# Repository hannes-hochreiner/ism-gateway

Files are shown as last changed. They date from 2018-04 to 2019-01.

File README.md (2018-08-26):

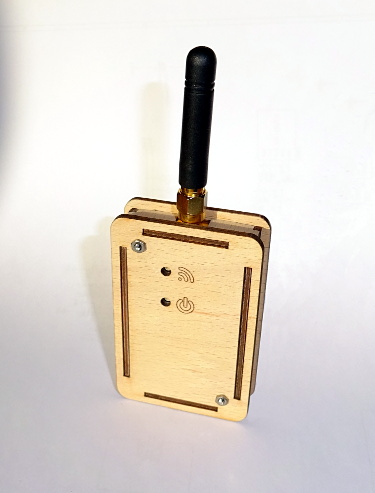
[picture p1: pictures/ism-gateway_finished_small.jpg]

# ism-gateway
A simple radio (434 MHz, ISM band) to USB gateway

## Firsts
The most exciting part of every project, are the things I have never done before.
This is a list of things that were new to me with this project:

  * USB (A/B micro connector, power and data)
  * RGB LEDs
  * LED controller with custom protocol
  * custom housing

## Housing
I had the housing laser cut from 2 mm plywood.
I assumed 0.1 mm of kerb, which worked fine for the most part.
The material seemed to be somewhat thicker than the advertised 2 mm or maybe just uneven.
Therefore, I had to file down side walls to make them fit into the holes of the top and bottom covers.
The cut-outs for the antenna, usb connector, LED, and threaded rods fit perfectly.
The case is held together by two threaded rods (M2) at opposite corners and fixed with nuts.
The rods also run through the mounting holes of the PCB.
Additional nuts are used to hold the PCB in place.

### Learnings
  * plywood cases look quite ok
  * 0.1 mm kerb is ok for 2 mm plywood
  * plywood is not necessarily exactly the nominal thickness
  * a metal file would be good to smooth the metal rod cut-faces

## Firmware
The firmware is based on code generated by the recommended STM tools.
I wrote custom drivers for the LED driver and the RFM98 module.
These drivers are able to operate in blocking or interrupt mode, depending on the functions provided by the calling code.

The LED driver is used in interrupt mode, currently.
The RFM98 is polled to check for newly received messages.

## Software
Any program that is able to read messages from generic CDC-ACM devices should be fine.
I wrote a small [monitoring program](https://github.com/hannes-hochreiner/usb-cdc-monitor) as a starting point.

### Ideas for improvement
  * the USB interrupts should be prioritized over the LED driver interrupts
  * interrupts should be used to check for received messages from the RFM98 module
  * USB messages should only be sent, if there is a receiver attached

## License
To all the parts that I developed, the MIT license applies.
Parts from third parties (e.g. generated code) may have other license restrictions.

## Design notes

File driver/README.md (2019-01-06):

# ISM-Gateway Driver
This is a simple driver to read messages from the ism-gateway and publish it to zeromq.

## Installation
The program can be compiled from source by running make:

```
make
```

### 3rd party libraries

#### libusb

```
sudo dnf install libusb-devel
```

#### Crypto++
The [Crypto++ Library](https://cryptopp.com) is used for decrypting the messages from the sensors.
```
sudo aptitude install libcrypto++-dev
```
or
```
sudo dnf install cryptopp-devel
```

#### JSON for Modern C++
[JSON for Modern C++](https://github.com/nlohmann/json) is used as stand-alone hpp-import.

#### ZeroMQ
The [C++ bindings for ZeroMQ](https://github.com/zeromq/cppzmq) are used.
Therefore, the czmq-library must be installed.

```
sudo dnf install czmq-devel
```
or
```
sudo apt install libczmq-dev
```

## Running
The program can be run from command line.
A decryption key needs to be supplied.

```
sudo ism-gateway-driver/bld/ism-gateway-driver -k <key> 2>/dev/null
```

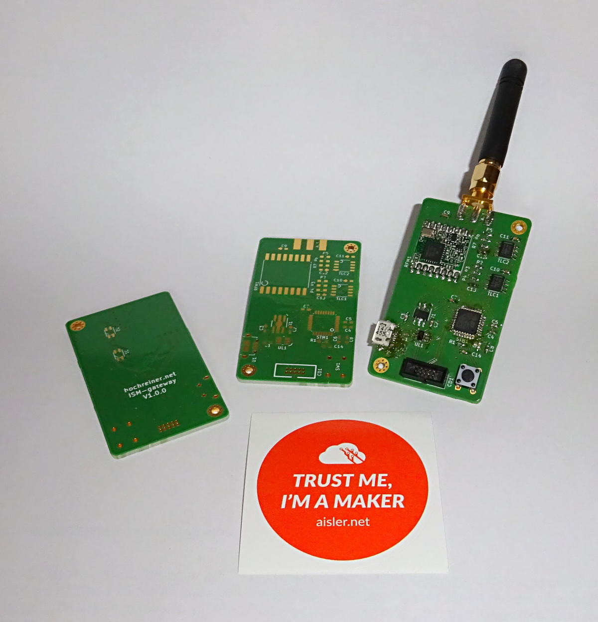
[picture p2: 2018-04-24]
pictures/pcbs.jpg

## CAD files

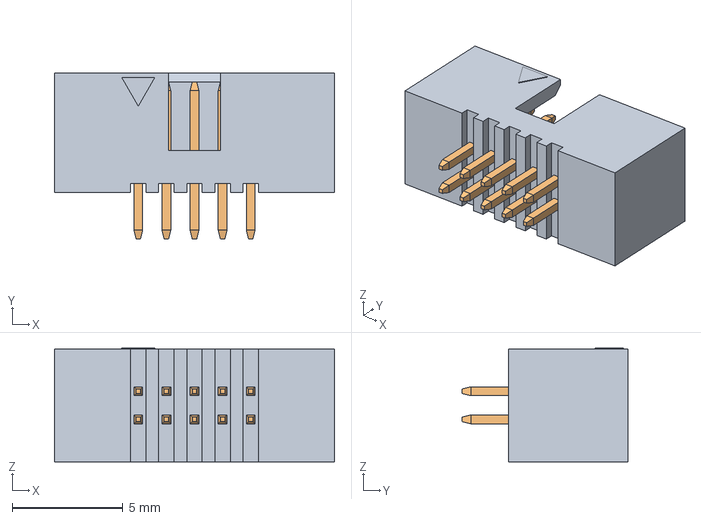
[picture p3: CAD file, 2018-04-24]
kicad/models/3220-10-0100.fcstd
12.7 x 7.50 x 5.13 mm

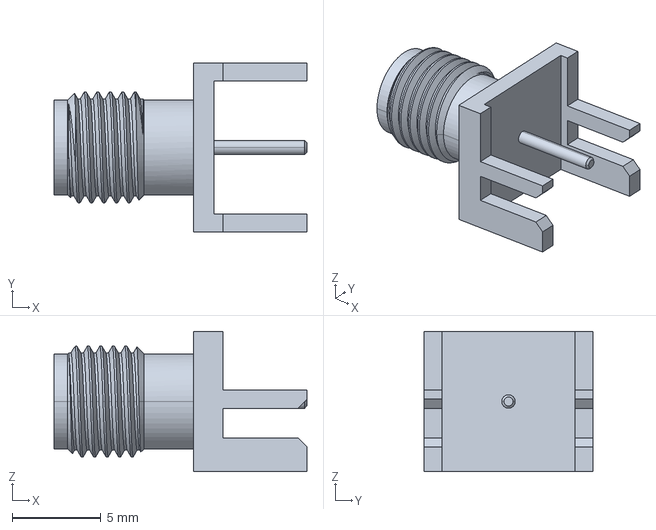
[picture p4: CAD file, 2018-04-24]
kicad/models/73251-1150.stp
14.3 x 9.53 x 7.92 mm

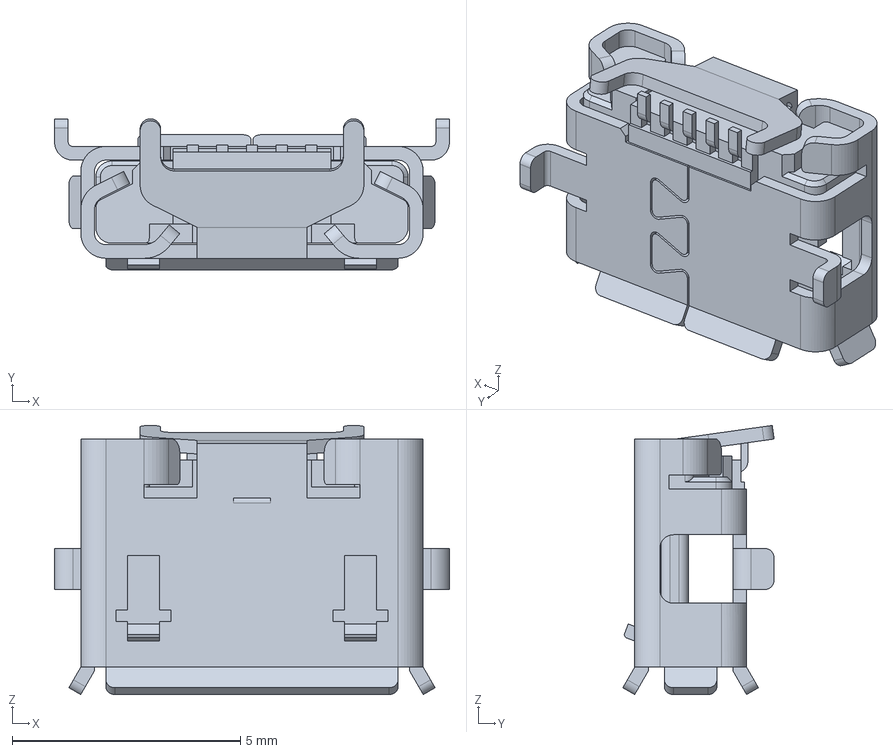
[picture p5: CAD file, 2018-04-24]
kicad/models/47589-0001.stp
8.65 x 3.31 x 5.89 mm

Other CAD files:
kicad/models/3220-10-0100.igs

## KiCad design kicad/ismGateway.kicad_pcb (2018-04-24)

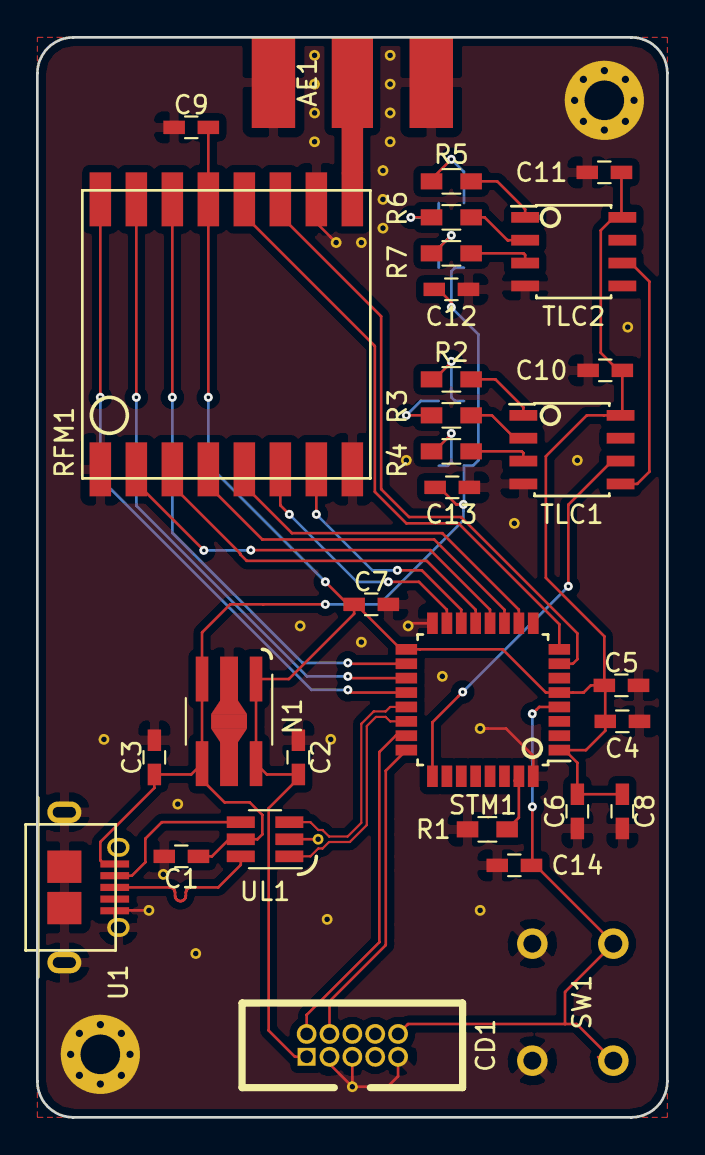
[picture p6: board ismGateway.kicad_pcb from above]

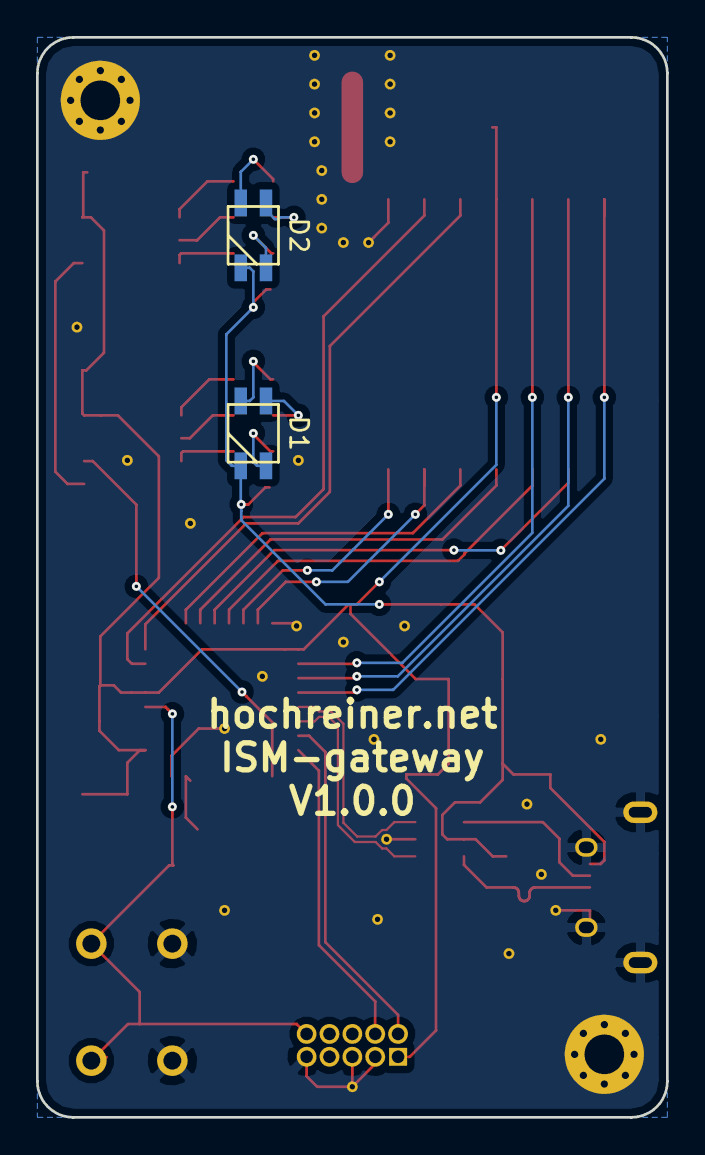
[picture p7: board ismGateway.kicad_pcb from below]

Board: 2 copper layers, 35.0 x 60.0 mm, 33 parts (2 on the bottom side), 37 nets.

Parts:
AE1: Antenna_Shield; MOLEX-0732511150
C1, C5, C6, C7, C9, C10, C11, C14: 0.1uF; C_0603_HandSoldering
C2, C3, C4: 1uF; C_0603_HandSoldering
C8, C12, C13: 10uF; C_0603_HandSoldering
CD1: CORTEX-DEBUG
D1, D2: LED_ARGB; CreePLCC4
N1: NCP4687-SOT-89; SOT89-5_Housing_Handsoldering
R1: 10k; R_0603_HandSoldering
R2, R3, R5, R6: 130; R_0603_HandSoldering
R4, R7: 150; R_0603_HandSoldering
RFM1: RFM98
STM1: STM32L062K8T6; LQFP-32_7x7mm_Pitch0.8mm
SW1: SW_Push; switch
TLC1, TLC2: TLC59731; SOIC-8_3.9x4.9mm_Pitch1.27mm
U1: USB_micro_ab; MOLEX_USB_MICRO_0475890001
UL1: USBLC6-2; SOT-23-6_Handsoldering

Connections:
/3V3: C2.2, C4.1, C5.1, C6.2, C7.1, C8.1, C9.2, C10.2, C11.2, CD1.1, N1.1, N1.5, RFM1.13, STM1.1, STM1.5, STM1.17, TLC1.8, TLC2.8
/LED_SDI: STM1.25, TLC1.6
/RFM_IO0: RFM1.14, STM1.18
/RFM_IO1: RFM1.15, STM1.19
/RFM_IO2: RFM1.16, STM1.20
/RFM_IO3: RFM1.11, STM1.7
/RFM_IO4: RFM1.12, STM1.8
/RFM_IO5: RFM1.7, STM1.14
/RFM_RESET: RFM1.6, STM1.15
/SPI_MISO: RFM1.2, STM1.12
/SPI_MOSI: RFM1.3, STM1.13
/SPI_NSS: RFM1.5, STM1.10
/SPI_SCK: RFM1.4, STM1.11
/SWCLK: CD1.4, STM1.24
/SWDIO: CD1.2, STM1.23
/SWD_NRST: C14.1, CD1.10, STM1.4, SW1.2
/USB_D+: STM1.22, UL1.1
/USB_D-: STM1.21, UL1.3
/VBUS: C1.1, C3.1, C12.1, C13.1, D1.1, D2.1, N1.3, N1.4, U1.1, UL1.5
GND: AE1.2, C1.2, C2.1, C3.2, C4.2, C5.2, C6.1, C7.2, C8.2, C9.1, C10.1, C11.1, C12.2, C13.2, C14.2, CD1.3, CD1.5, CD1.9, N1.2, R1.2, RFM1.1, RFM1.8, RFM1.10, STM1.16, STM1.32, SW1.1, TLC1.4, TLC2.4, U1.5, UL1.2
unnamed: AE1.1, RFM1.9
unnamed: D1.2, R4.2
unnamed: D1.3, R3.2
unnamed: D1.4, R2.2
unnamed: D2.2, R7.2
unnamed: D2.3, R6.2
unnamed: D2.4, R5.2
unnamed: R1.1, STM1.31
unnamed: R2.1, TLC1.1
unnamed: R3.1, TLC1.2
unnamed: R4.1, TLC1.3
unnamed: R5.1, TLC2.1
unnamed: R6.1, TLC2.2
unnamed: R7.1, TLC2.3
unnamed: TLC1.5, TLC2.6
unnamed: U1.2, UL1.4
unnamed: U1.3, UL1.6

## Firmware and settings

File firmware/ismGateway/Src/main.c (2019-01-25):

/**
  ******************************************************************************
  * @file           : main.c
  * @brief          : Main program body
  ******************************************************************************
  * This notice applies to any and all portions of this file
  * that are not between comment pairs USER CODE BEGIN and
  * USER CODE END. Other portions of this file, whether 
  * inserted by the user or by software development tools
  * are owned by their respective copyright owners.
  *
  * Copyright (c) 2018 STMicroelectronics International N.V. 
  * All rights reserved.
  *
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
  ******************************************************************************
  */
/* Includes ------------------------------------------------------------------*/
#include "main.h"
#include "stm32l0xx_hal.h"
#include "aes.h"
#include "spi.h"
#include "tim.h"
#include "usb_device.h"
#include "gpio.h"

/* USER CODE BEGIN Includes */
#include "usbd_cdc_if.h"
#include "rfm9x_glue.h"
/* USER CODE END Includes */


/* USER CODE BEGIN PV */
typedef enum {
  TIMER_PENDING,
  TIMER_DONE
} timer_status_t;
volatile timer_status_t timer_status = TIMER_DONE;
volatile color_t colorSystem = {0x00, 0x03, 0x00};
volatile color_t colorTransmit = {0x00, 0x03, 0x00};
const color_t COLOR_RED = {0x03, 0x00, 0x00};
const color_t COLOR_GREEN = {0x00, 0x03, 0x00};
const color_t COLOR_BLUE = {0x00, 0x00, 0x03};
const color_t COLOR_YELLOW = {0x03, 0x03, 0x00};
/* USER CODE END PV */

void SystemClock_Config(void);

/* USER CODE BEGIN PFP */

/* USER CODE END PFP */

/**
  * @brief  The application entry point.
  *
  * @retval None
  */
int main(void)
{
  /* MCU Configuration----------------------------------------------------------*/

  /* Reset of all peripherals, Initializes the Flash interface and the Systick. */
  HAL_Init();

  /* Configure the system clock */
  SystemClock_Config();

  /* Initialize all configured peripherals */
  MX_GPIO_Init();
  MX_SPI1_Init();
  MX_TIM2_Init();
  MX_USB_DEVICE_Init();
  MX_AES_Init();
  /* USER CODE BEGIN 2 */
  rfm9x_g_init();

  bitbang_calls_t led_calls = {led_delay, led_set_pin, led_reset_pin};
  SetColors(&led_calls, &colorSystem, &colorTransmit);

  LL_DBGMCU_EnableDBGSleepMode();
  LL_DBGMCU_EnableDBGStopMode();
  LL_DBGMCU_EnableDBGStandbyMode();

  LL_PWR_SetPowerMode(LL_PWR_MODE_STANDBY);

  rfm9x_flags_t flags;
  const rfm9x_flags_t flags_all = RFM9X_FLAG_ALL;
  rfm9x_g_start_reception_mode();
  /* USER CODE END 2 */

  /* Infinite loop */
  /* USER CODE BEGIN WHILE */
  while (1)
  {
    // while (LL_GPIO_IsInputPinSet(RFM_IO0_GPIO_Port, RFM_IO0_Pin) == 1) {
      rfm9x_g_get_flags(&flags);

      if ((flags & RFM9X_FLAG_RX_DONE) && !(flags & RFM9X_FLAG_PAYLOAD_CRC_ERROR)) {
        rfm9x_g_get_message(ReadData);
        colorTransmit = COLOR_BLUE;
        SetColors(&led_calls, &colorSystem, &colorTransmit);
        LL_mDelay(50);
        colorTransmit = COLOR_GREEN;
      } else {
        colorTransmit = COLOR_YELLOW;
      }

      rfm9x_g_reset_flags(&flags_all);
      SetColors(&led_calls, &colorSystem, &colorTransmit);
    // }
    LL_mDelay(100);

    // __WFI();
  /* USER CODE END WHILE */

  /* USER CODE BEGIN 3 */

  }
  /* USER CODE END 3 */

}

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
/* USER CODE BEGIN 4 */
void led_set_pin() {
  LL_GPIO_SetOutputPin(LED_SDI_GPIO_Port, LED_SDI_Pin);
}

void led_reset_pin() {
  LL_GPIO_ResetOutputPin(LED_SDI_GPIO_Port, LED_SDI_Pin);
}

void led_delay() {
  timer_status = TIMER_PENDING;
  LL_TIM_EnableIT_UPDATE(TIM2);
  LL_TIM_EnableCounter(TIM2);

  while(timer_status == TIMER_PENDING) {
    __WFI();
  }

  LL_TIM_DisableCounter(TIM2);
  LL_TIM_DisableIT_UPDATE(TIM2);
}

void ReadData(int16_t rssi, const uint8_t* const data, uint8_t length) {
  uint8_t statusUSB = USBD_OK;

  uint8_t msg[length + 2];
  
  memcpy((char*)(msg), (const char*)&rssi, 2);
  memcpy((char*)(msg + 2), (const char*)data, length);

  if ((hUsbDeviceFS.dev_state == USBD_STATE_CONFIGURED) || (hUsbDeviceFS.dev_state == USBD_STATE_SUSPENDED)) {
    statusUSB = CDC_Transmit_FS(msg, length + 2);
  }

  if (statusUSB == USBD_OK) {
    colorSystem = COLOR_GREEN;
  } else if (statusUSB == USBD_BUSY) {
    colorSystem = COLOR_BLUE;
  } else if (statusUSB == USBD_FAIL) {
    colorSystem = COLOR_RED;
  } else {
    colorSystem = COLOR_YELLOW;
  }
}

void SetColors(const bitbang_calls_t* const calls, const color_t* const cSystem, const color_t* const cTransmit) {
  color_t colors[2] = {*cSystem, *cTransmit};
  set_colors(calls, colors, 2);
}

void TIMER_Callback() {
  timer_status = TIMER_DONE;
}
/* USER CODE END 4 */
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


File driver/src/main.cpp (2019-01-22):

#include "main.h"

int main(int argc, char const *argv[])
{
  try {
    args args(argc, argv);

    uint16_t vendor_id = 0x0483;
    uint16_t product_id = 0x5740;

    std::cout << "looking for devices...\n";

    usb_session session;
    std::list<usb_device> list = session.get_device_list();

    list.remove_if([vendor_id, product_id](usb_device dev) {
      return (dev.get_vendor_id() != vendor_id) || (dev.get_product_id() != product_id);
    });

    std::cout << list.size() << " device";
  
    if (list.size() != 1) {
      std::cout << "s";
    }
  
    std::cout << " found\n";

    if (list.size() > 1) {
      throw usb_exception("found more than one device");
    } else if (list.size() == 0) {
      throw usb_exception("no device found");
    }
    
    usb_device& dev = list.front();

    dev.open();
    std::cout << "device opened\n";
    dev.claim();
    std::cout << "device claimed\n";
    dev.control_transfer(0x21, ACM_REQUEST_SET_CONTROL_LINE_STATE, ACM_CTRL_DTR | ACM_CTRL_RTS, 0, NULL, 0, 0);
    unsigned char encoding[] = { 0x80, 0x25, 0x00, 0x00, 0x00, 0x00, 0x08 };
    dev.control_transfer(0x21, ACM_REQUEST_SET_LINE_CODING, 0, 0, encoding, sizeof(encoding), 0);

    int buffer_size = 64;
    int transfer_size;
    unsigned char buffer_data[buffer_size];
    aes_ecb aes(args.get_key());

    zmq::context_t context(1);
    zmq::socket_t publisher(context, ZMQ_PUB);

    publisher.bind("tcp://*:5555");

    while (true) {
      try {
        dev.bulk_transfer(EP_IN_ADDR, buffer_data, buffer_size, &transfer_size, 1000);
        std::cout << "received " << transfer_size << " bytes\n";

        int16_t rssi;

        memcpy((void *)&rssi, (void *)buffer_data, 2);

        if (transfer_size % 4 == 2) {
          unsigned char buffer_decrypt_data[transfer_size - 2];

          aes.decrypt((buffer_data + 2), buffer_decrypt_data, transfer_size - 2);

          if (buffer_decrypt_data[0] == 1) {
            message_0001_t* msg = (message_0001_t*)(buffer_decrypt_data);

            std::string msg_json = format_message_1(rssi, msg);
            std::cout << msg_json << "\n";
            zmq::message_t msg_zmq(msg_json.c_str(), msg_json.size());

            publisher.send(msg_zmq);
          } else if (buffer_decrypt_data[0] == 2) {
            message_0002_t* msg = (message_0002_t*)(buffer_decrypt_data);

            std::string msg_json = format_message_2(rssi, msg);
            std::cout << msg_json << "\n";
            zmq::message_t msg_zmq(msg_json.c_str(), msg_json.size());

            publisher.send(msg_zmq);
          } else {
            std::cout << "unknown message type received\n";
          }
        } else {
          std::cout << "unexpected data length " << transfer_size << "\n";
        }
      } catch (const usb_exception_pipe& ex) {
        std::cerr << "usb exception: " << ex.what() << "\n";
        dev.clear_halt(EP_IN_ADDR);
      } catch (const usb_exception& ex) {
        std::cerr << "usb exception: " << ex.what() << "\n";
      }
    }
  }
  catch(const std::exception& e)
  {
    std::cerr << e.what() << '\n';
    return 1;
  }  

  return 0;
}

std::string format_message_1(const int16_t& rssi, message_0001_t const *const msg) {
  json j;

  j["rssi"] = rssi;
  j["timestamp"] = get_timestamp();
  j["message"]["type"] = msg->type;
  j["message"]["mcu_id"] = mcu_id_to_hex(msg->mcu_id_1, msg->mcu_id_2, msg->mcu_id_3);
  j["message"]["message_index"] = msg->message_index;
  j["message"]["sensor_id"] = sensor_id_to_hex(msg->sensor_id);
  j["message"]["humidity"] = msg->humidity;
  j["message"]["temperature"] = msg->temperature;

  return j.dump();
}

std::string format_message_2(const int16_t& rssi, message_0002_t const *const msg) {
  json j;

  j["rssi"] = rssi;
  j["timestamp"] = get_timestamp();
  j["message"]["type"] = msg->type;
  j["message"]["mcu_id"] = mcu_id_to_hex(msg->mcu_id_1, msg->mcu_id_2, msg->mcu_id_3);
  j["message"]["message_index"] = msg->message_index;
  j["message"]["sensor_id"] = sensor_id_to_hex(msg->sensor_id);
  j["message"]["humidity"] = msg->humidity;
  j["message"]["temperature"] = msg->temperature;
  j["message"]["pressure"] = msg->pressure;

  return j.dump();
}

std::string get_timestamp() {
  time_t now;
  time(&now);
  char buf[sizeof("YYYY-MM-DDTHH:MM:SSZ")];
  strftime(buf, sizeof(buf), "%FT%TZ", gmtime(&now));

  return std::string(buf);
}

std::string sensor_id_to_hex(uint16_t sensor_id) {
  std::ostringstream os;

  os.width(4);
  os.fill('0');
  os << std::hex << std::uppercase << sensor_id;

  return os.str();
}

std::string mcu_id_to_hex(uint32_t mcu_id_1, uint32_t mcu_id_2, uint32_t mcu_id_3) {
  std::ostringstream os;

  os.width(8);
  os.fill('0');
  os << std::hex << std::uppercase << mcu_id_3 << "-" << mcu_id_2 << "-" << mcu_id_1;

  return os.str();
}

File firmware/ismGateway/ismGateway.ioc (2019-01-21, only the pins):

Mcu.UserName=STM32L062K8Tx
PA11.Signal=USB_DM
PA12.Signal=USB_DP
PA13.Signal=SYS_SWDIO
PA14.Signal=SYS_SWCLK
PA15.GPIO_Label=LED_SDI
PA15.Signal=GPIO_Output
PA4.GPIO_Label=SPI1_NSS
PA4.Signal=GPIO_Output
PA5.Signal=SPI1_SCK
PA6.Signal=SPI1_MISO
PA7.Signal=SPI1_MOSI
PA8.GPIO_Label=RFM_IO0
PA8.Signal=GPXTI8
PB1.GPIO_Label=RFM_RESET
PB1.Signal=GPIO_Output

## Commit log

2018-04-24 added kicad files
    [3220-10-0100.fcstd, 3220-10-0100.igs, 47589-0001.stp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]
2018-04-28 added housing
2018-05-01 added firmware
    [stm32.cfg]
2018-08-22 added debug target
    [oo.cfg]
2018-08-26 switched to using interrupts from rfm module
2018-08-26 refactored LED functions
2018-08-26 based radio state check on pin state
2018-11-10 started work on driver
2018-11-10 added device iteration
2018-12-29 removed dead code and added an rfm reset
    [main.c]
2018-12-29 switch to memcpy
2019-01-01 switched from rust to c++
2019-01-06 improved makefile and error reporting
    [main.cpp]
2019-01-21 switched to LoRa
2019-01-21 fixed a wrong pointer
    [main.c]
2019-01-21 fixed the message length
    [main.c]
2019-01-22 switched to reporting unexpected lengths

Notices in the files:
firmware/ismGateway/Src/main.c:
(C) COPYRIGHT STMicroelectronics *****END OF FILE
